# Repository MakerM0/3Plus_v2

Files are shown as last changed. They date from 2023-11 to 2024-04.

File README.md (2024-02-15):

# 3Plus_v2
a macro keyboard

[OSHWHUB](https://oshwhub.com/kakaka/Multi-function-macro-keyboard-3Plus20-version)

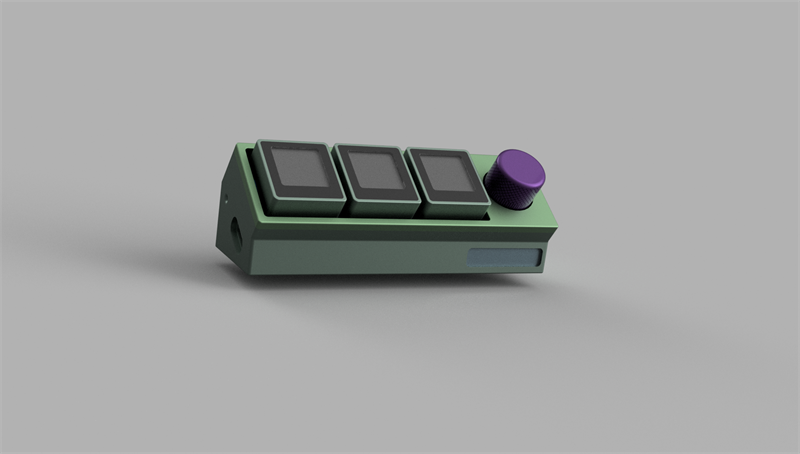
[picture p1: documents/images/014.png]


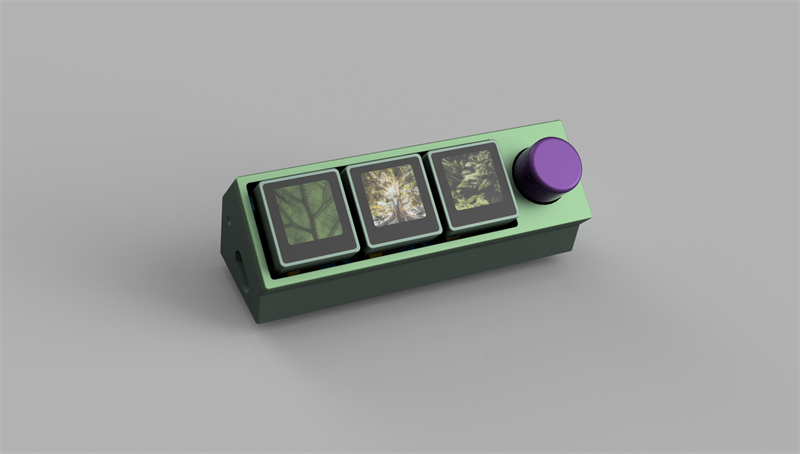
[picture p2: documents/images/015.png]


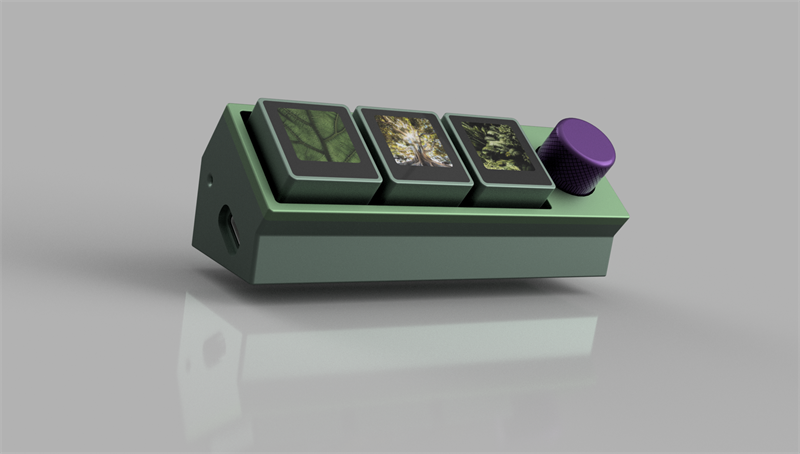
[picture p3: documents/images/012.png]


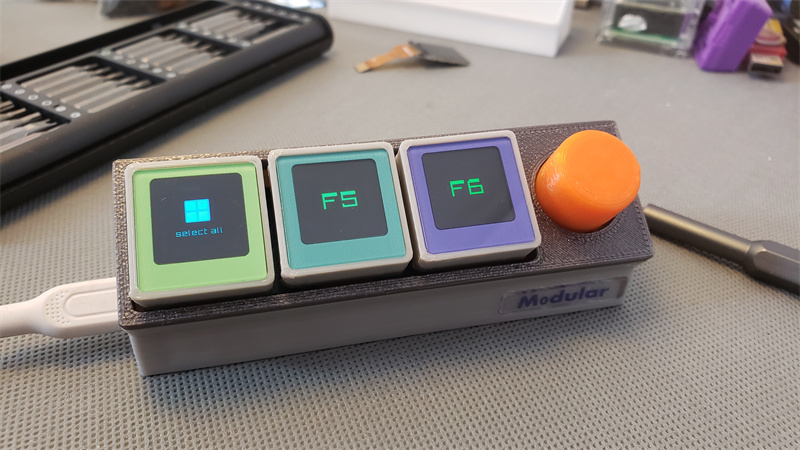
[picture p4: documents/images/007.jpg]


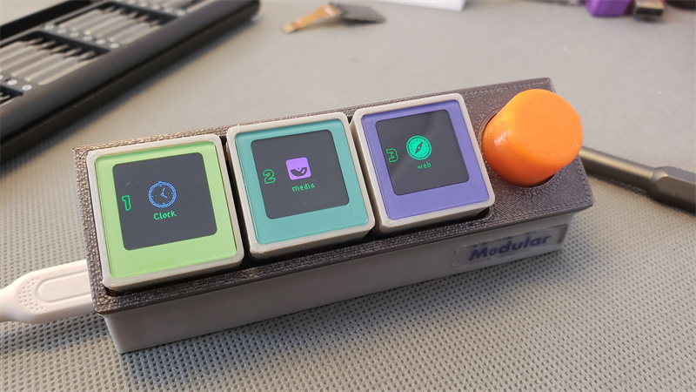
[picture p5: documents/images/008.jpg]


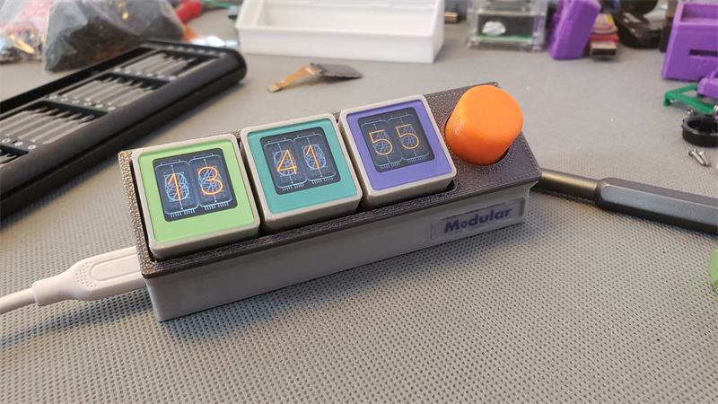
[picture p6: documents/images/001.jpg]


## Mechanical

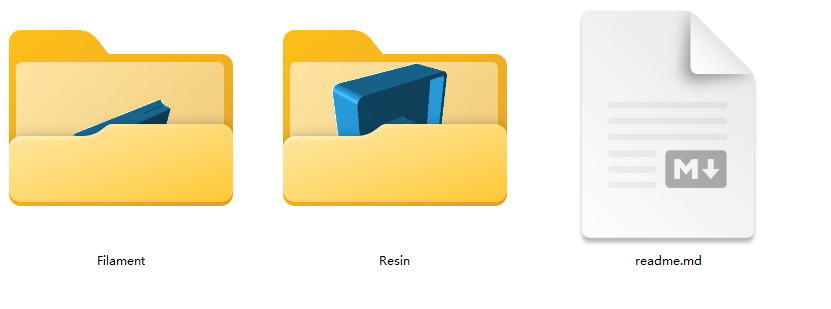
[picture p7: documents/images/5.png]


## License

(documents/hardware/mechanical)[Creative Commons — Attribution-NonCommercial-ShareAlike 4.0 International — CC BY-NC-SA 4.0](https://creativecommons.org/licenses/by-nc-sa/4.0/)

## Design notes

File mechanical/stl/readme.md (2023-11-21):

# Resin

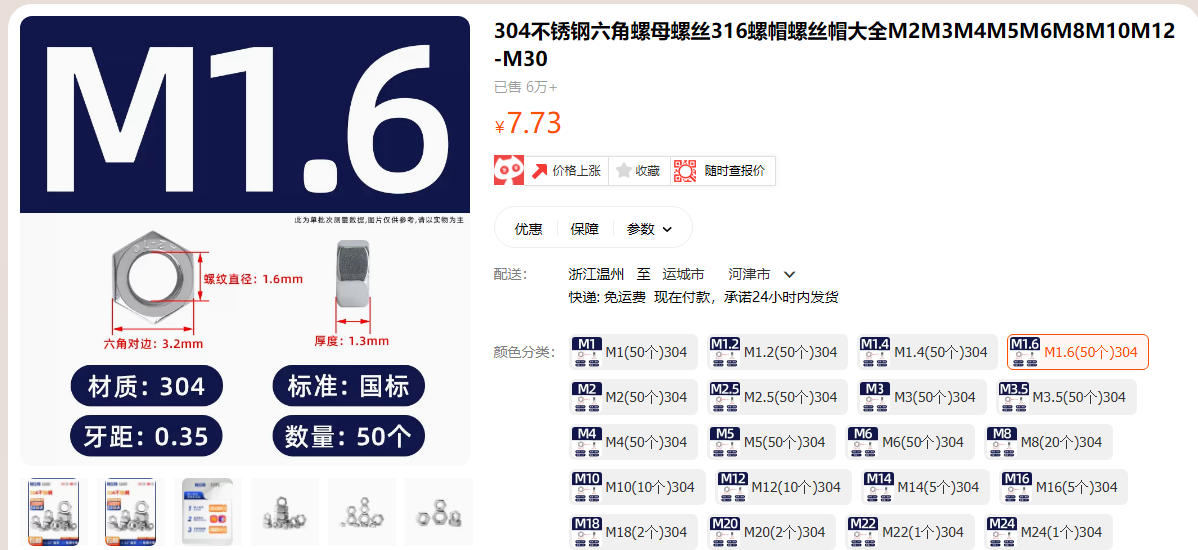
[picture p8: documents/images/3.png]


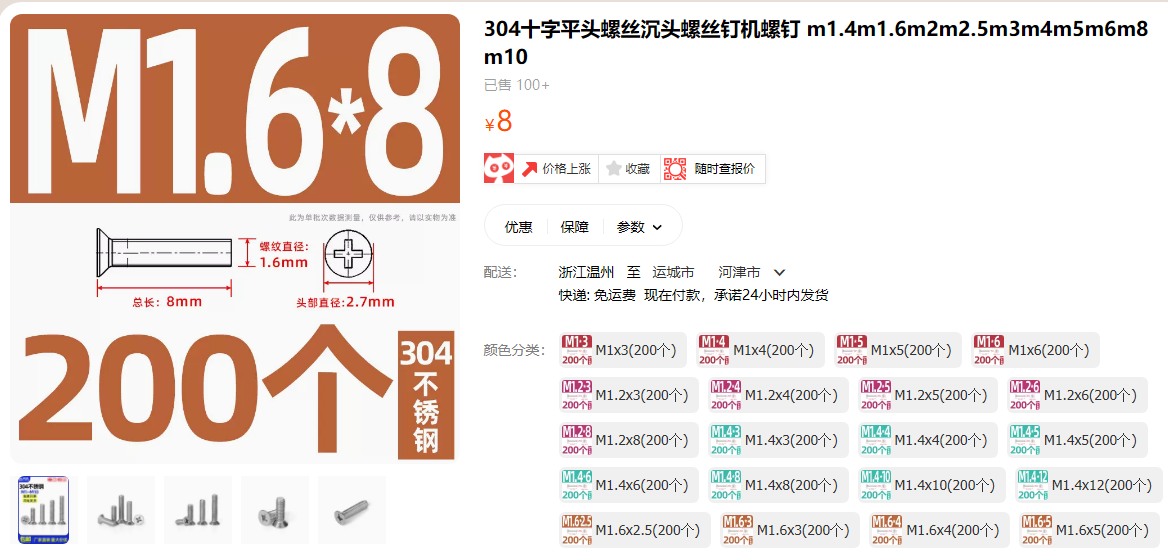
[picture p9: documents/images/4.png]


# Filament

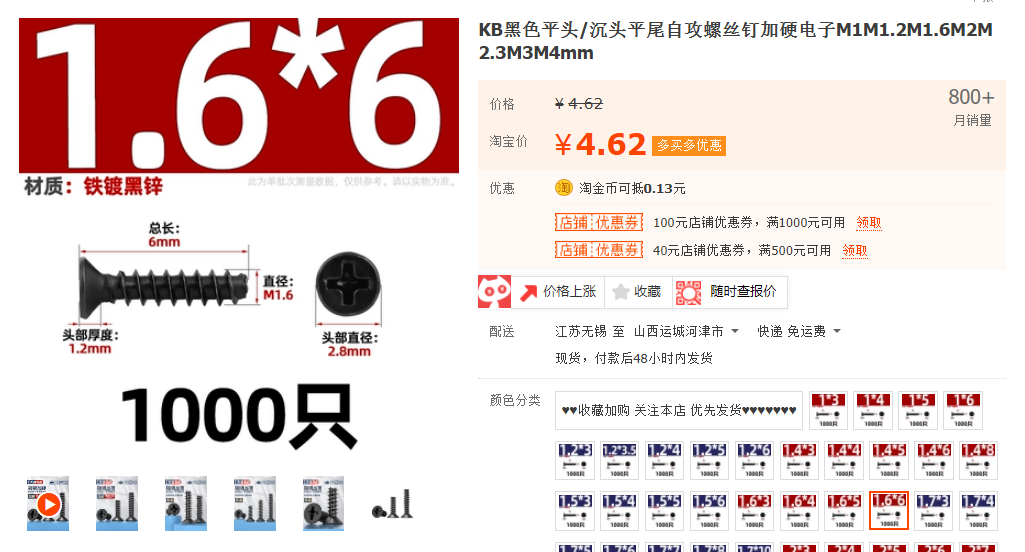
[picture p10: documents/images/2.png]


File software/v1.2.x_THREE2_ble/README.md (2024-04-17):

[多功能宏键盘 3Plus 【V2版本】 - 嘉立创EDA开源硬件平台 (oshwhub.com)](https://oshwhub.com/kakaka/Multi-function-macro-keyboard-3Plus20-version)

## 更新历史

### 20220901 【v1.0.0】

- 初始版本
- 时钟图片来源于https://github.com/JosueAGtz/displayArray/

### 20221024 【v1.0.2】

- 时钟增加1分钟随机切换显示，防烧屏
- 增加网络配置城市和wifi，通过重启状态下按下左数第三个按键
- 增加全字母键盘功能页
- 增加一键三连等
- 增加番茄钟
- spiffs迁移到littlefs
- 支持S3、C3

### 20221117 【v1.0.3】

- 增加三款时钟类型，时钟图片来源于https://github.com/JosueAGtz/displayArray/
- 修复一些小bug
- 增加几个网站快捷

### 20221125 【v1.0.4】

- 判断wifi的ssid等参数是否有填充

### 20221207 【v1.1.0】

- 使用WiFiManager修改wifi等参数
- 时钟类型自动添加
- 时钟部分重新修改，调整尺寸和类型，受限于资源区大小，时钟类型进行了缩减，只留下了我常用的
- 修复以前的一些bug
- 如果没有填充天气相关信息，请不要使用天气功能，可能会重启的
- 增加OTA升级，开机时，一直按住左数第三个按键，直到第三个屏幕出现OTA字样即可
- 如果想重新配置WIFI，开机时，一直按住左数第二个按键，屏幕会有提示

### 20231114 【v1.1.1】

- 增加esp32s3的支持，硬件升级为v2版本
- 更新部分库
- 使用WiFiManager修改wifi等参数
- 时钟图片大小调整
- 如果没有填充天气相关信息，请不要使用天气功能，可能会重启的
- 增加OTA升级，开机后，在出现三键客字样时，一直按住左数第3个按键，直到第三个屏幕出现OTA字样即可
- 如果想重新配置WIFI，开机时，一直按住左数第2个按键，屏幕会有提示
- 如果想进入boot模式，需在开机上电前按住左数第3个按键

### 20231121 【v1.2.0】

- 屏蔽天气、pcstate
- 增加宏定义控制audio的使用，在platform.ini中进行开关
- 快捷键，可以自定义按键，填充数组内容即可
- audio存在一个bug，若播放声音后，boot按钮（左数第三个）会失效；暂时解决，待后续跟进
- 在时钟界面，会整点报时

### 20240319 【v1.2.1】

- 添加led灯效

### 20240320 【v1.2.2】

- 修复web页面输入错误问题

### 20240417 【v1.2.3】

- 更新图形库arduino_gfx 1.4.6
- 在wifi配置页面增加编码器的参数配置（一般为2或者4）
- 显示界面的字体调整
- 显示屏增加OTA进度条指示
- b站界面调整

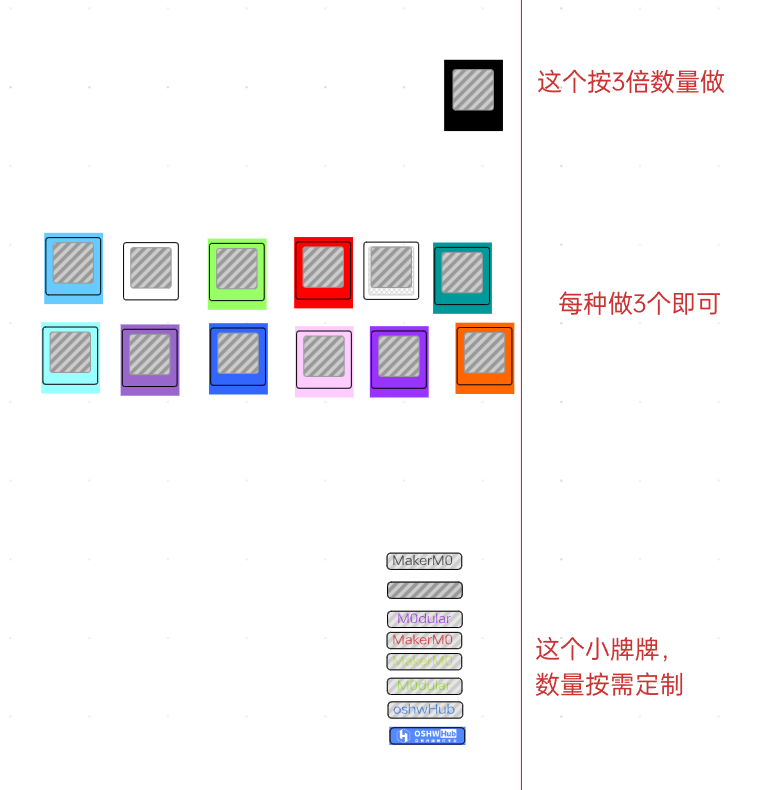
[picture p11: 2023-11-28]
mechanical/pannel/note.png

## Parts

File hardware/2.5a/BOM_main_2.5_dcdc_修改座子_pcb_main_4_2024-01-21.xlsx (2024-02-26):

No. | Quantity | Designator | Footprint | Manufacturer Part | Manufacturer | Supplier | Supplier Part | Value | Comment | JLCPCB Part Class
1 | 8 | C4,C5,C7,C8,C9,C206,C209,C211 | C0603 | CL10B104KB8NNNC | SAMSUNG(三星) | LCSC | C1591 | 100nF | 100nF | Extended Part
2 | 3 | C6,C10,C11 | C0603 | CL10A106KP8NNNC | SAMSUNG(三星) | LCSC | C19702 | 10uF | 10uF | Basic Part
3 | 3 | C204,C205,C213 | C0603 | CL10A105KB8NNNC | SAMSUNG(三星) | LCSC | C15849 | 1uF | 1uF | Basic Part
4 | 2 | C207,C210 | C0805 | CL21A226MAQNNNE | SAMSUNG(三星) | LCSC | C45783 | 22uF | 22uF | 基础库
5 | 1 | C208 | C0603 | CL10C220JB8NNNC | SAMSUNG(三星) | LCSC | C1653 | 22pF | 22pF | 基础库
6 | 2 | C214,C215 | C1206 | GRM31CR61A476ME15L | muRata(村田) | LCSC | C94034 | 47uF | 47uF | Extended Part
7 | 1 | D1 | sod-323_l1.8-w1.3-ls2.5-rd | 1N5819WS | Hottech(合科泰) | LCSC | C191023 |  | 1N5819WS | Basic Part
8 | 3 | FPC1,FPC2,FPC3 | FPC-SMD_12P-P0.50_FPC-05F-12PH20 | FPC-05F-12PH20 | XUNPU(讯普) | LCSC | C2856799 |  | FPC-05F-12PH20 | Extended Part
9 | 1 | L5 | IND-SMD_L4.0-W4.0 | YNR4030-2R2M | YJYCOIN(益嘉源) | LCSC | C340389 | 2.2uH | 2.2uH | Extended Part
10 | 1 | LED1 | LED0603-R-RD | 19-217/R6C-AL1M2VY/3T | EVERLIGHT(台湾亿光) | LCSC | C72044 |  | 19-217/R6C-AL1M2VY/3T | Extended Part
11 | 3 | LED2,LED3,LED4 | LED-SMD_4P-L4.0-W1.7_M4020-03003-RGB-862-001 | XL-4020RGBC-WS2812B | XINGLIGHT(成兴光) | LCSC | C3647024 |  | XL-4020RGBC-WS2812B | Extended Part
12 | 3 | MX1,MX2,MX3 | CherryMX(KHS)-1.00U | CPG151101S11-16 | Kailh(凯华) | LCSC | C5156480 |  | CPG151101S11-16 | Extended Part
13 | 1 | Q1 | SOT-23-3_L2.9-W1.3-P1.90-LS2.4-BR | AO3415 | Hottech(合科泰) | LCSC | C181094 |  | AO3415 | Extended Part
14 | 1 | Q200 | SOT-23-3_L2.9-W1.3-P1.90-LS2.4-BR | SS8050 | CJ（江苏长电/长晶） | LCSC | C2150 |  | SS8050 | BasicPart
15 | 2 | R1,R2 | R0603 | 0603WAF5101T5E | UNI-ROYAL(厚声) | LCSC | C23186 | 5.1kΩ | 5.1kΩ | Basic Part
16 | 4 | R5,R9,R10,R202 | R0603 | 0603WAF1002T5E | UNI-ROYAL(厚声) | LCSC | C25804 | 10kΩ | 10kΩ | Basic Part
17 | 4 | R13,R209,R214,R215 | R0603 | 0603WAF1003T5E | UNI-ROYAL(厚声) | LCSC | C25803 | 100kΩ | 100kΩ | Basic Part
18 | 2 | R16,R201 | R0603 | 0603WAF1001T5E | UNI-ROYAL(厚声) | LCSC | C21190 | 1kΩ | 1kΩ | Basic Part
19 | 1 | R204 | R0603 | 0603WAF1004T5E | UNI-ROYAL(厚声) | LCSC | C22935 | 1MΩ | 1MΩ | 基础库
20 | 3 | R205,R206,R207 | R0603 | 0603WAF200JT5E | UNI-ROYAL(厚声) | LCSC | C22950 | 20Ω | 20Ω | Basic Part
21 | 1 | R208 | R0603 | 0603WAF1501T5E | UNI-ROYAL(厚声) | LCSC | C22843 | 1.5kΩ | 1.5kΩ | Basic Part
22 | 1 | R211 | R0603 | 0603WAF2212T5E | UNI-ROYAL(厚声) | LCSC | C25961 | 22.1kΩ | 22.1kΩ | Extended Part
23 | 1 | SW102 | SW-SMD_EC11J1524413 | EC11J1524413 | ALPSALPINE(阿尔卑斯阿尔派) | LCSC | C470592 |  | EC11J1524413 | 扩展库
24 | 1 | SW111 | SW-TH_SK12D07VG4 | SK12D07VG4 | SHOU HAN(首韩) | LCSC | C393937 |  | SK12D07VG4 | Extended Part
25 | 1 | U1 | sot-23-5_l3.0-w1.7-p0.95-ls2.8-br | TP4054-42-SOT25R | TOPPOWER(南京拓微) | LCSC | C32574 |  | TP4054-42-SOT25R | Basic Part
26 | 1 | U205 | WIRELM-SMD_ESP32-S3-WROOM-1 | ESP32-S3-WROOM-1-N8R2 | ESPRESSIF(乐鑫) | LCSC | C2913204 |  | ESP32-S3-WROOM-1-N8R2 | Extended Part
27 | 1 | U206 | SOT-23-5_L3.0-W1.7-P0.95-LS2.8-BL | SY8088IAAC | silergy(矽力杰) | LCSC | C479072 |  | SY8088IAAC | 扩展库
28 | 1 | U207 | ESOP-8_L4.9-W3.9-P1.27-LS6.0-BL-EP-1 | NS4168 |  | LCSC | C9900042517 |  | NS4168
29 | 1 | USB2 | USB-C_SMD-TYPE-C-31-M-12 | USB-TYPE-C-018 | DEALON(德艺隆) | LCSC | C2927038 |  | USB-TYPE-C-018 | Extended Part

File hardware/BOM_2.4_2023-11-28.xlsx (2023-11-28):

No. | Quantity | Designator | Footprint | Manufacturer Part | Manufacturer | Supplier | Supplier Part | Value | Comment | JLCPCB Part Class
1 | 4 | C1,C2,C204,C205 | C0603 | CL10A105KB8NNNC | SAMSUNG(三星) | LCSC | C15849 | 1uF | 1uF | Basic Part
2 | 6 | C4,C5,C7,C8,C9,C35 | C0603 | CL10B104KB8NNNC | SAMSUNG(三星) | LCSC | C1591 | 100nF | 100nF | Extended Part
3 | 4 | C6,C10,C11,C34 | C0603 | CL10A106KP8NNNC | SAMSUNG(三星) | LCSC | C19702 | 10uF | 10uF | Basic Part
4 | 2 | C47,C48 | C0603 | 0603B681K500NT | FH(风华) | LCSC | C1630 | 680pF | 680pF | Basic Part
5 | 1 | D1 | sod-323_l1.8-w1.3-ls2.5-rd | 1N5819WS | Hottech(合科泰) | LCSC | C191023 |  | 1N5819WS | Basic Part
6 | 3 | FPC1,FPC2,FPC3 | CONN-SMD_12P-P0.50_L3.1-W8.0 | AFC42-S12FMA-1H | JS(钜硕电子) | LCSC | C466532 |  | AFC42-S12FMA-1H | 扩展库
7 | 2 | L3,L4 | L0603 | BLM18SG331TN1D | muRata(村田) | LCSC | C88989 |  | BLM18SG331TN1D | Extended Part
8 | 1 | LDO1 | SOT-23-5_L3.0-W1.7-P0.95-LS2.8-BR | TLV75733PDBVR | TI(德州仪器) | LCSC | C485517 |  | TLV75733PDBVR | Extended Part
9 | 1 | LED1 | LED0603-R-RD | 19-217/R6C-AL1M2VY/3T | EVERLIGHT(台湾亿光) | LCSC | C72044 |  | 19-217/R6C-AL1M2VY/3T | Extended Part
10 | 3 | MX1,MX2,MX3 | CherryMX(KHS)-1.00U | CPG151101S11-16 | Kailh(凯华) | LCSC | C5156480 |  | CPG151101S11-16 | Extended Part
11 | 1 | Q1 | sot-23-3_l2.9-w1.3-p1.90-ls2.4-br | AO3415 | Hottech(合科泰) | LCSC | C181094 |  | AO3415 | Extended Part
12 | 1 | Q200 | SOT-23-3_L2.9-W1.3-P1.90-LS2.4-BR | SS8050 | CJ（江苏长电/长晶） | LCSC | C2150 |  | SS8050 | BasicPart
13 | 2 | R1,R2 | R0603 | 0603WAF5101T5E | UNI-ROYAL(厚声) | LCSC | C23186 | 5.1kΩ | 5.1kΩ | Basic Part
14 | 4 | R5,R9,R10,R202 | R0603 | 0603WAF1002T5E | UNI-ROYAL(厚声) | LCSC | C25804 | 10kΩ | 10kΩ | Basic Part
15 | 2 | R13,R43 | R0603 | 0603WAF1003T5E | UNI-ROYAL(厚声) | LCSC | C25803 | 100kΩ | 100kΩ | Basic Part
16 | 3 | R16,R201,R208 | R0603 | 0603WAF1001T5E | UNI-ROYAL(厚声) | LCSC | C21190 | 1kΩ | 1kΩ | Basic Part
17 | 1 | R42 | R0603 | RC0603FR-07634KL | YAGEO(国巨) | LCSC | C273753 | 634kΩ | 634kΩ | Extended Part
18 | 1 | R204 | R0603 | 0603WAF1004T5E | UNI-ROYAL(厚声) | LCSC | C22935 | 1MΩ | 1MΩ | 基础库
19 | 3 | R205,R206,R207 | R0603 | 0603WAF200JT5E | UNI-ROYAL(厚声) | LCSC | C22950 | 20Ω | 20Ω | Basic Part
20 | 1 | SW102 | SW-SMD_EC11J1524413 | EC11J1524413 | ALPSALPINE(阿尔卑斯阿尔派) | LCSC | C470592 |  | EC11J1524413 | 扩展库
21 | 1 | SW104 | SW-SMD_TS36CA | TS36CA-0.6 | SHOU HAN(首韩) | LCSC | C2681481 |  | TS36CA-0.6 | 扩展库
22 | 3 | SW105,SW106,SW107 | KEY-TH_CPG1511F01S0X | CPG151101S13 | Kailh(凯华) | LCSC | C404353 |  | CPG151101S13 | 扩展库
23 | 1 | U1 | SOT-23-5_L3.0-W1.7-P0.95-LS2.8-BR | TP4054-42-SOT25R | TOPPOWER(南京拓微) | LCSC | C32574 |  | TP4054-42-SOT25R | Basic Part
24 | 1 | U15 | TQFN-16_L3.0-W3.0-P0.50-BL-EP1.5 | MAX98357AETE+T | ADI(亚德诺)/MAXIM(美信) | LCSC | C910544 |  | MAX98357AETE+T | Extended Part
25 | 1 | U205 | WIRELM-SMD_ESP32-S3-WROOM-1 | ESP32-S3-WROOM-1-N8R2 | ESPRESSIF(乐鑫) | LCSC | C2913204 |  | ESP32-S3-WROOM-1-N8R2 | Extended Part
26 | 1 | USB2 | USB-C_SMD-TYPE-C-31-M-12 | USB-TYPE-C-018 | DEALON(德艺隆) | LCSC | C2927038 |  | USB-TYPE-C-018 | Extended Part

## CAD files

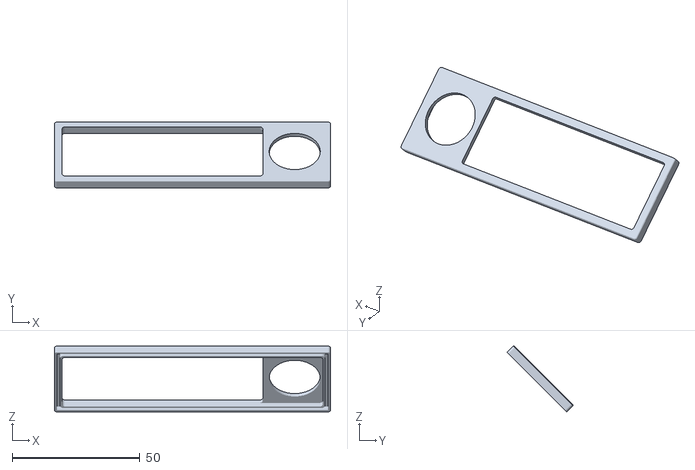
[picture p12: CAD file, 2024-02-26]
mechanical/stl/2.5/盖板.stl
108.0 x 25.7 x 25.7

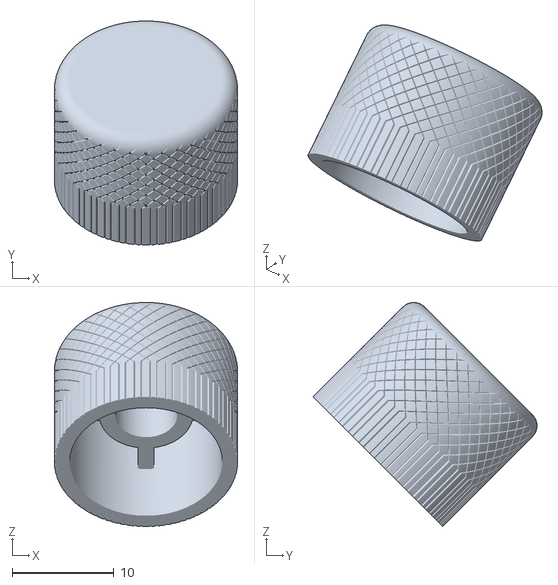
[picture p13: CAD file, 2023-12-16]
mechanical/stl/Filament/plus_旋钮_纹理_pla.stl
18.0 x 22.0 x 22.0

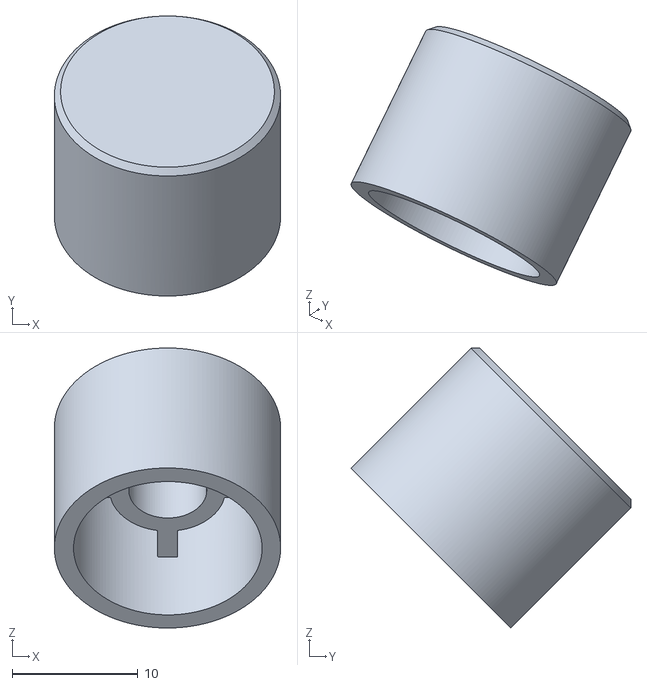
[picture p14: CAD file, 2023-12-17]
mechanical/stl/Resin/旋钮_光面_内孔扩大0.1mm.stl
18.0 x 22.3 x 22.3

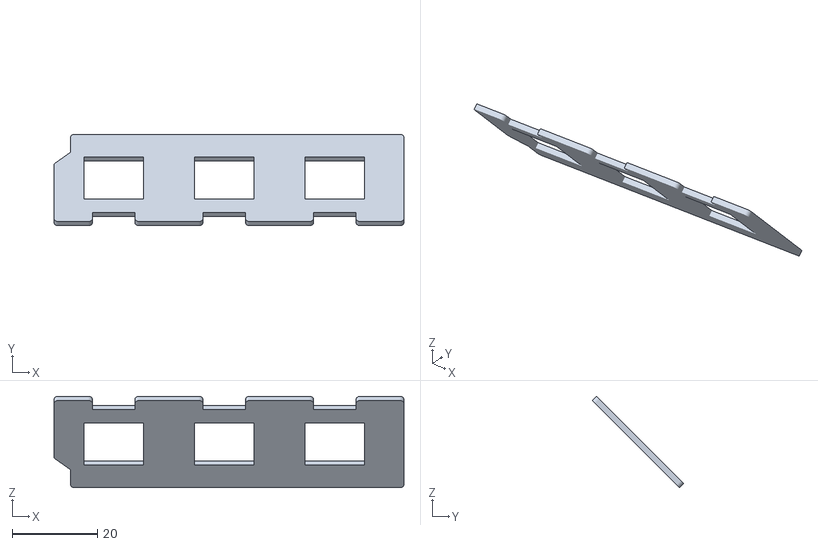
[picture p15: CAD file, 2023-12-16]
mechanical/stl/定位板_1.4mm.stl
82.3 x 21.5 x 21.5

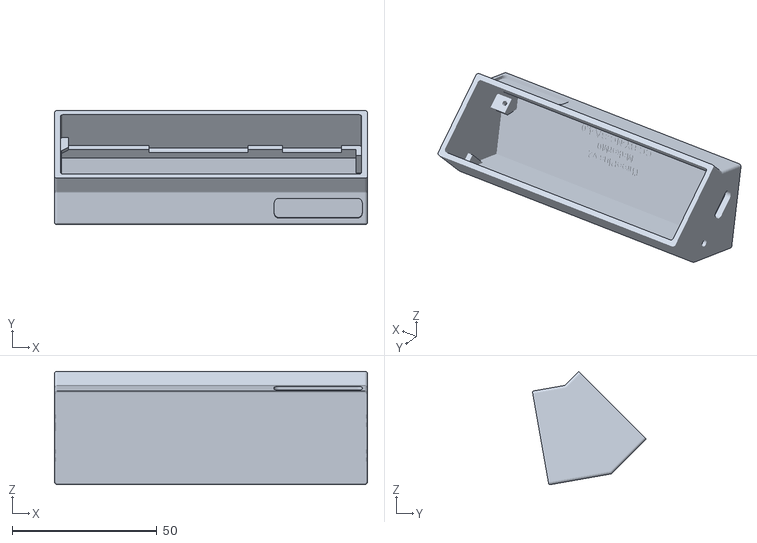
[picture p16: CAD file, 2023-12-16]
mechanical/stl/方案3/filament/plus_外壳 _pla_面板_与亚克力盖板配合.stl
108.0 x 39.3 x 39.1

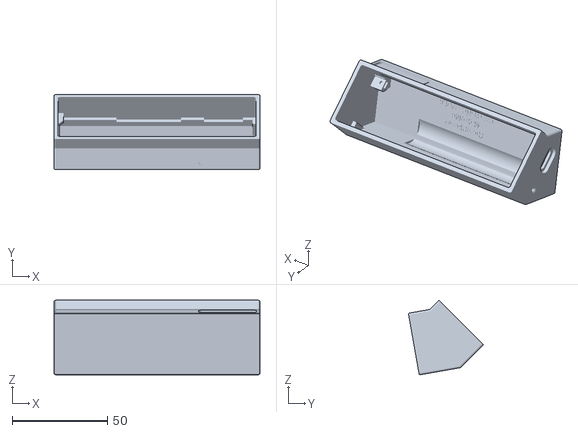
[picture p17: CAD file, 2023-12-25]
mechanical/stl/方案3/光固化/外壳 _面板_与亚克力盖板配合_14650带保护板锂电池.stl
108.0 x 39.3 x 39.1

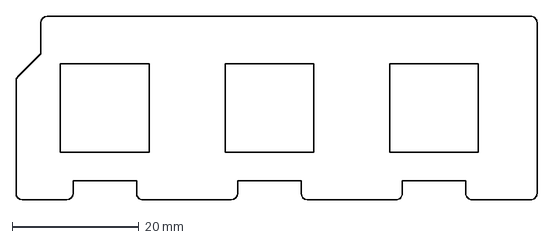
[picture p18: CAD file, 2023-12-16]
mechanical/stl/方案3/定位板.dxf
82.3 x 29.0 mm

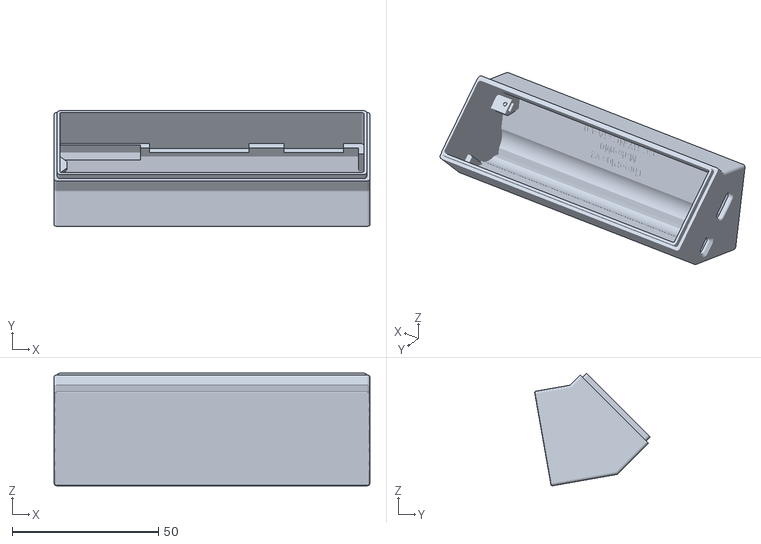
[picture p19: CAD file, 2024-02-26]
mechanical/stl/2.5/外壳.stl
108.0 x 39.5 x 38.5

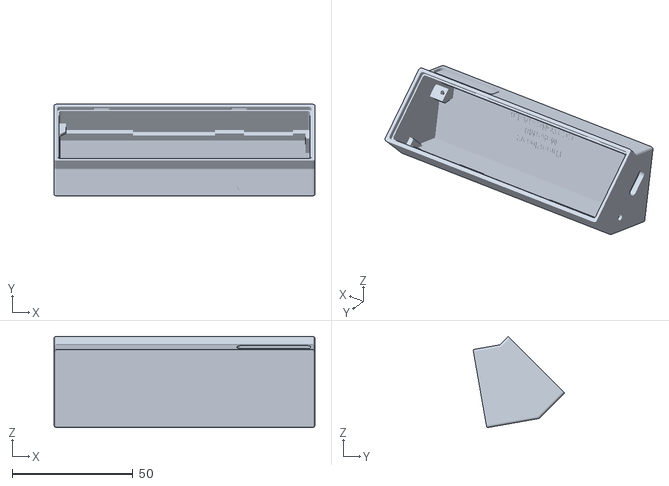
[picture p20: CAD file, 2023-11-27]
mechanical/stl/Filament/plus_外壳 _面板_pla.stl
108.0 x 37.9 x 37.7

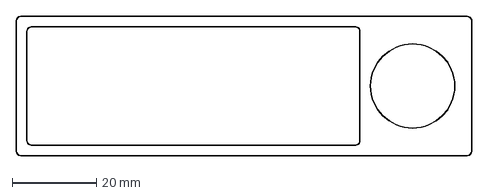
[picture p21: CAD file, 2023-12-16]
mechanical/stl/方案3/盖板-亚克力面板1.0mm.dxf
108.0 x 33.0 mm

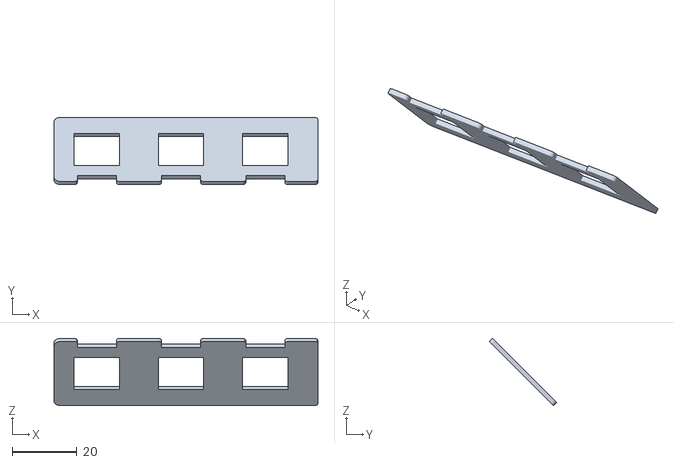
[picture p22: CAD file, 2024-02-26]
mechanical/stl/2.5/定位板.stl
81.5 x 20.8 x 20.8

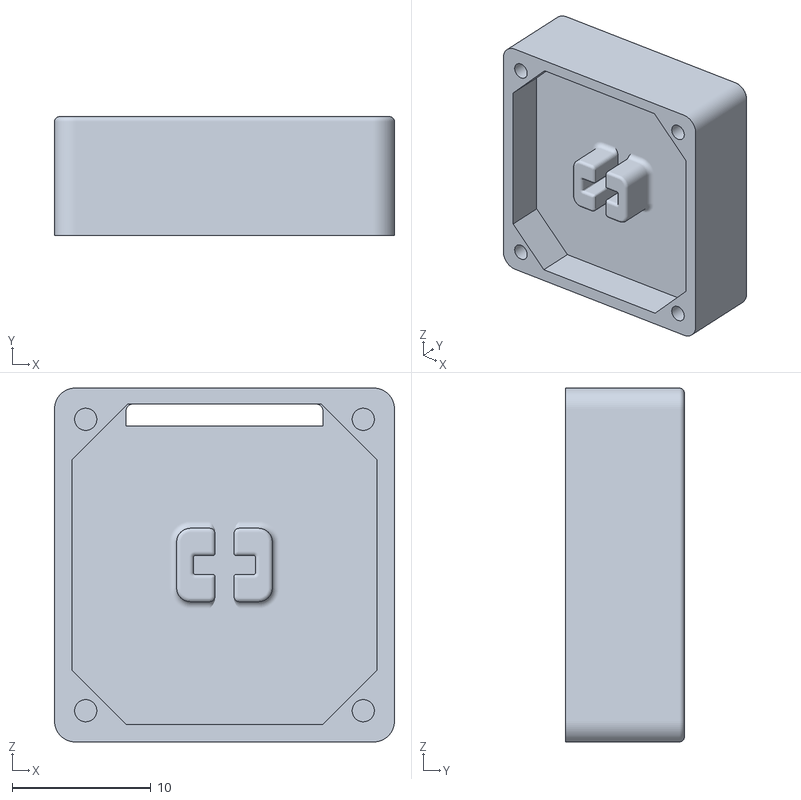
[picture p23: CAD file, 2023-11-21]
mechanical/stl/Filament/显示外壳 X3.stl
24.5 x 8.55 x 25.5

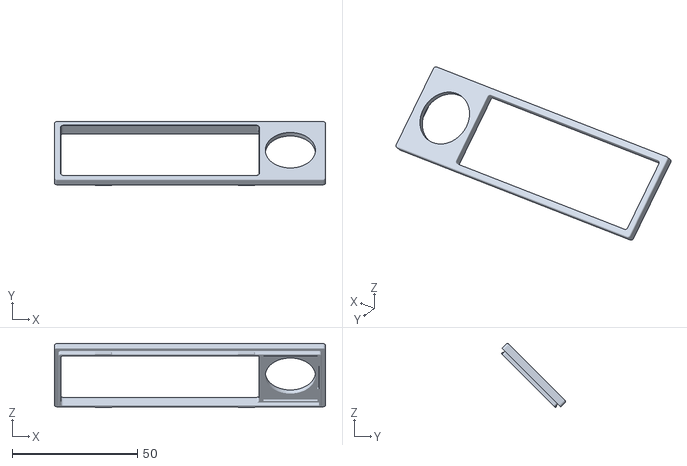
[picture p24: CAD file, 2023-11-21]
mechanical/stl/Filament/plus_盖板_pla.stl
108.0 x 25.5 x 25.5

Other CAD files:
mechanical/stl/Resin/旋钮_纹理_内孔扩大0.1mm.stl
mechanical/stl/方案3/光固化/外壳 _面板_与亚克力盖板配合.stl
mechanical/stl/Resin/外壳 _面板.stl
mechanical/stl/2.5/旋钮_光面.stl
mechanical/stl/Resin/外壳_刻字.stl
mechanical/stl/2.5/显示外壳 x3.stl
mechanical/stl/Resin/旋钮_光面_2.4.stl
mechanical/stl/Resin/旋钮_纹理_2.4.stl
mechanical/stl/Resin/盖板.stl

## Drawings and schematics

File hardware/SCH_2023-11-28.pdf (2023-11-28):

## VSYS

## VSYS

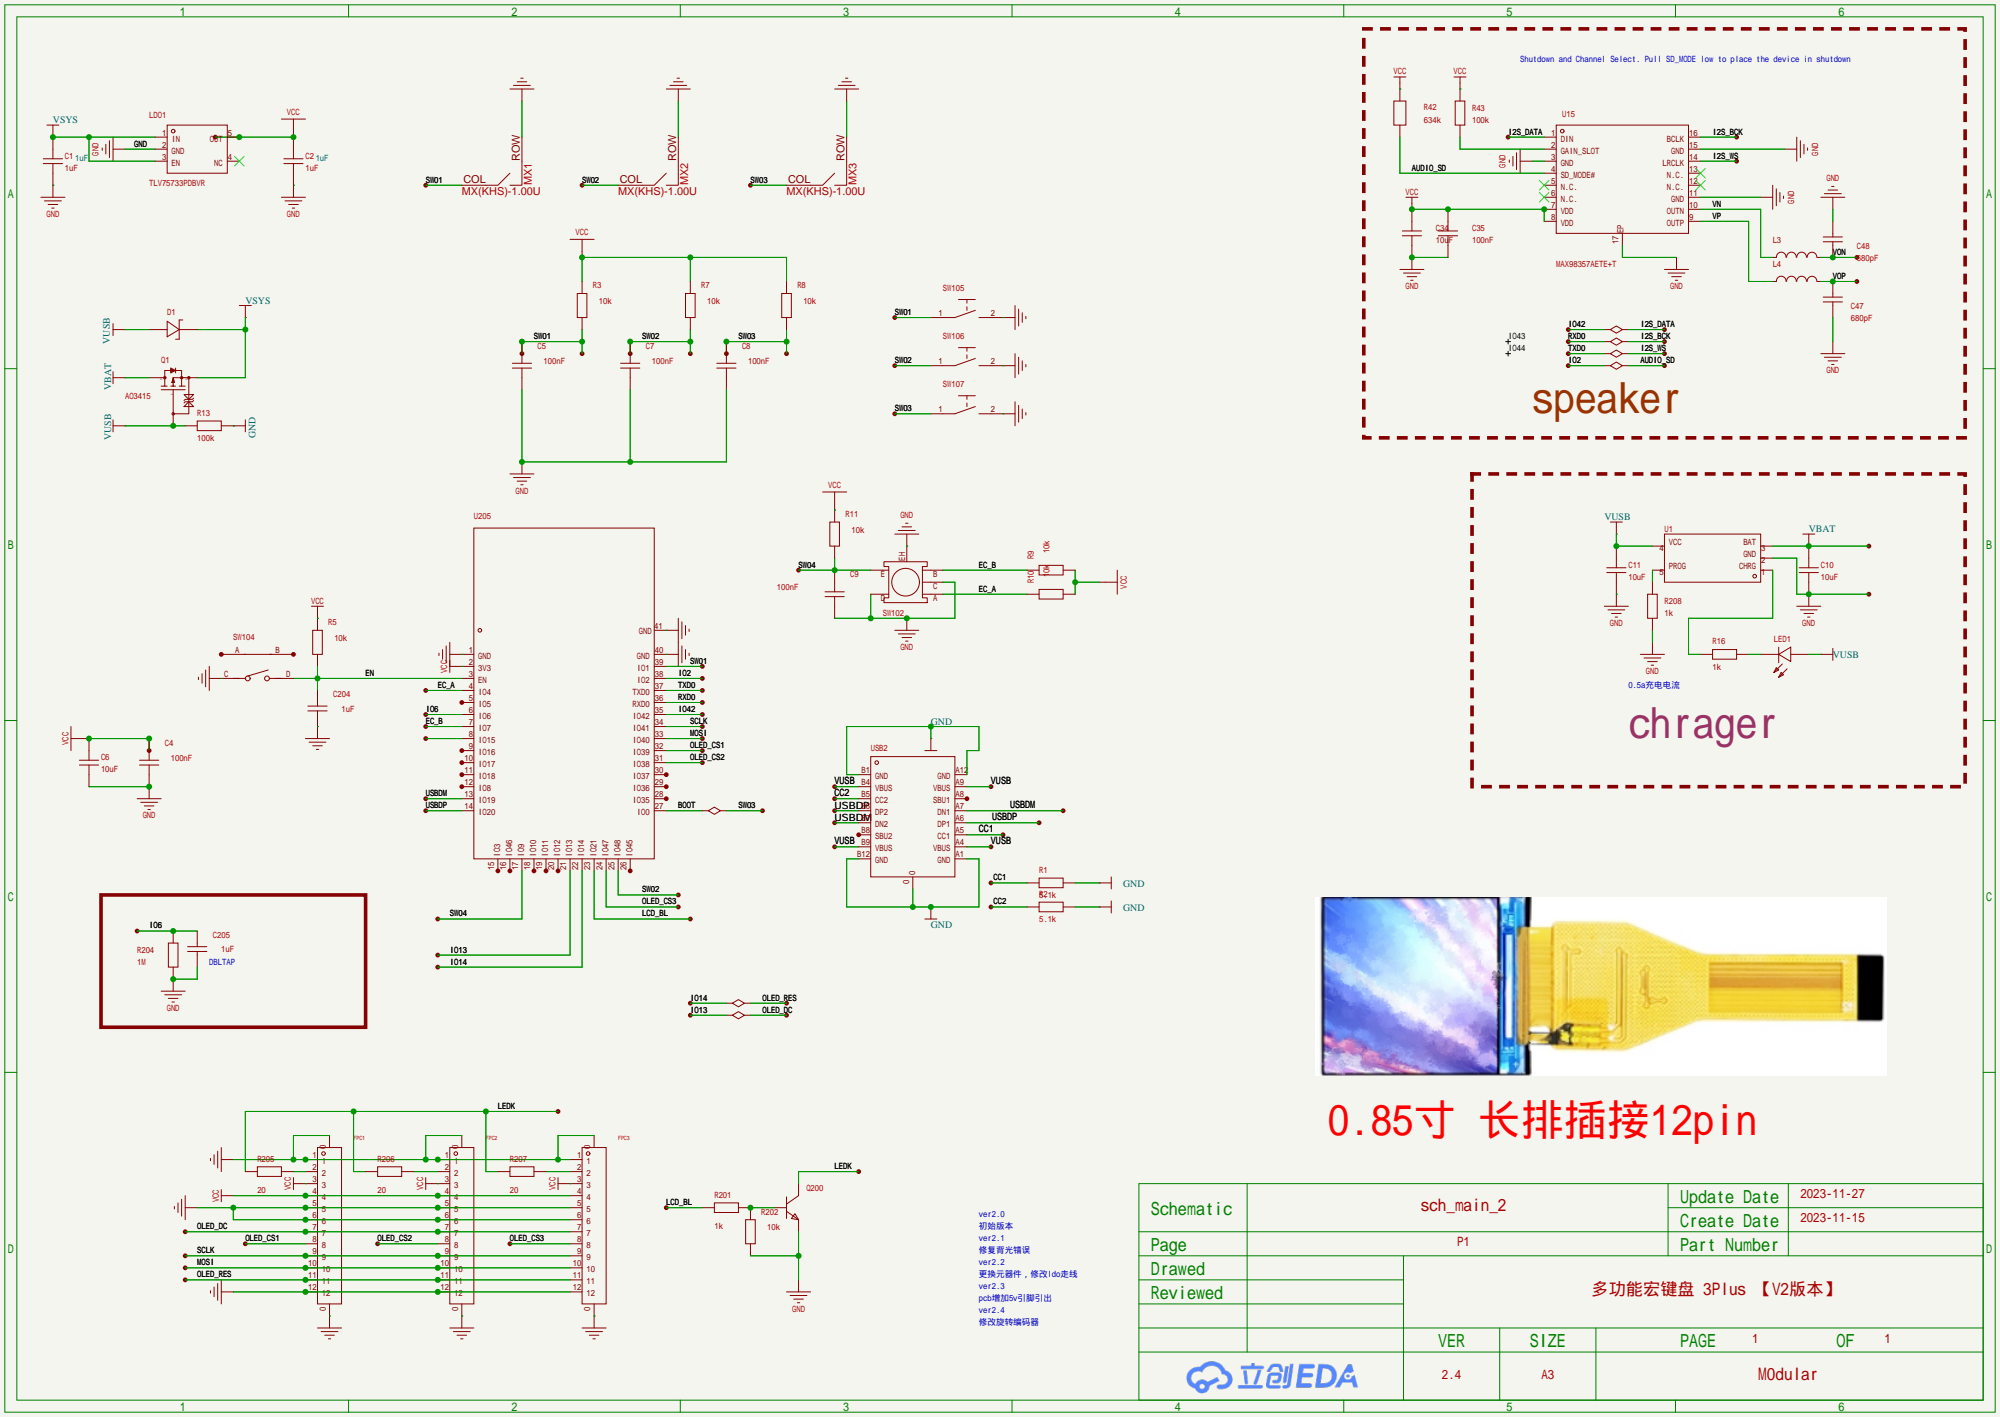
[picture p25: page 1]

Shutdown and Channel Select. Pull SD_MODE low to place the device in shutdown

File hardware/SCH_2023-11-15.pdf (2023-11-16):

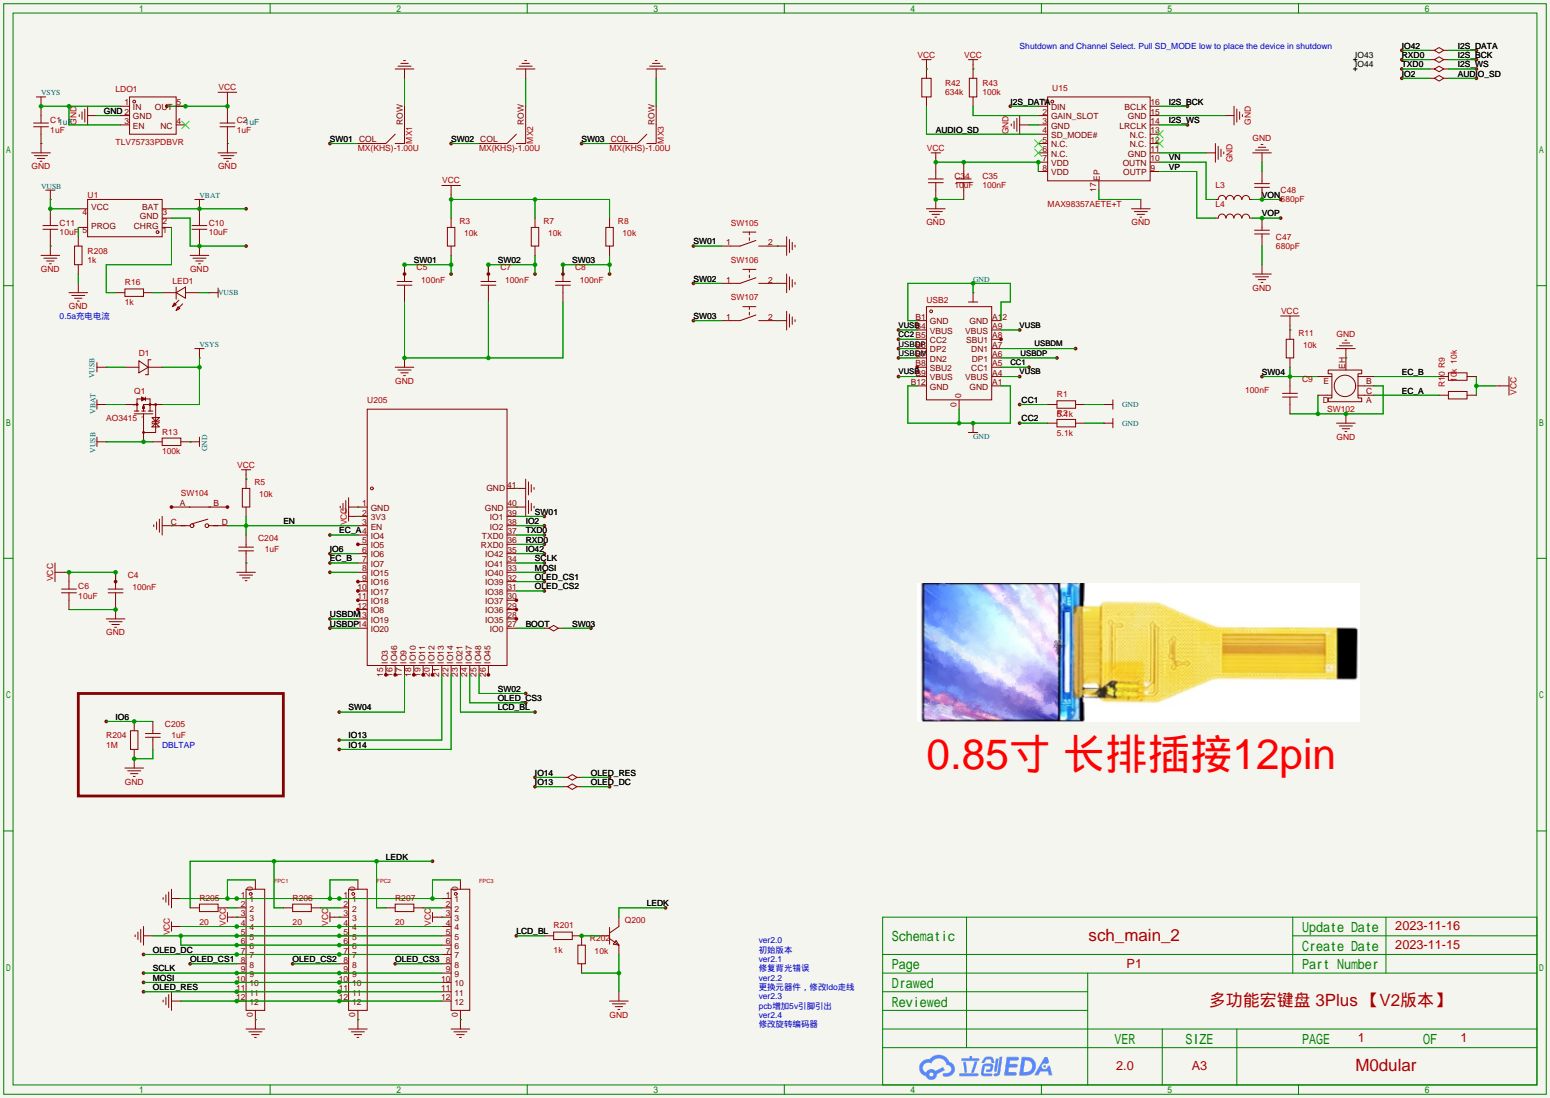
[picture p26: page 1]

Shutdown and Channel Select. Pull SD_MODE low to place the device in shutdown

OUTN 10 GND 11 N.C. 12 N.C. 13 LRCLK 14 GND 15 BCLK 16

GND A1 VBUS A4 CC1 A5 DP1 A6 DN1 A7 SBU1 A8 VBUS A9 GND A12

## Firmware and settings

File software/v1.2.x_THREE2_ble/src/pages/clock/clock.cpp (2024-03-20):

#include "clock.h"
#include "board_def.h"
#include "app/app_key.h"
#include "app/app_audio.h"
#include "app/app_led.h"
const char *number_name[] = {"zero", "one", "two", "three", "four", "five", "six", "seven", "eight", "nine"};
// char *clock_name[] = {"matrix", "nixie", "vfd", "digital", "14seg", "bina", "flip", "ink", "purple", "cyan", "nimo", "wood", "pixiepro", "predator", "rgb", "dhf"};

String clock_name[36];
static uint8_t CLOCK_TYPE_MAX = 0;
static int8_t clock_type_index ;
bool f_updateall = false;
static uint8_t num_old[6] = {0xff, 0xff, 0xff, 0xff, 0xff, 0xff};

#define POS_Y 0

static uint8_t xpos=64;

void dispTime(uint8_t hour, uint8_t min, uint8_t sec)
{
	char path[100];

	// gfx1->setCursor(0, 0);
	// gfx1->setTextSize(8);
	// gfx1->setTextColor(random(0xffff), BLACK);
	// gfx1->printf("%02d", hour);
	// gfx1->draw16bitBeRGBBitmap(0, POS_Y, (uint16_t *)clock_img[hour / 10], xpos, 96);
	// gfx1->draw16bitBeRGBBitmap(xpos, POS_Y, (uint16_t *)clock_img[hour % 10], xpos, 96);
	if (num_old[0] != hour / 10 || f_updateall)
	{
		num_old[0] = hour / 10;
		sprintf(path, "/clock_theme/%s/%s.png", clock_name[clock_type_index], number_name[hour / 10]);
		myDrawPNG(0, POS_Y, path, 0);
	}
	if (num_old[1] != hour % 10 || f_updateall)
	{
		num_old[1] = hour % 10;
		sprintf(path, "/clock_theme/%s/%s.png", clock_name[clock_type_index], number_name[hour % 10]);
		myDrawPNG(xpos, POS_Y, path, 0);
	}

	// gfx2->setCursor(0, 0);
	// gfx2->setTextSize(8);
	// gfx2->setTextColor(random(0xffff), BLACK);
	// gfx2->printf("%02d", min);
	// gfx2->draw16bitBeRGBBitmap(0, POS_Y, (uint16_t *)clock_img[min / 10], xpos, 96);
	// gfx2->draw16bitBeRGBBitmap(xpos, POS_Y, (uint16_t *)clock_img[min % 10], xpos, 96);
	if (num_old[2] != min / 10 || f_updateall)
	{
		num_old[2] = min / 10;
		sprintf(path, "/clock_theme/%s/%s.png", clock_name[clock_type_index], number_name[min / 10]);
		myDrawPNG(0, POS_Y, path, 1);
	}
	if (num_old[3] != min % 10 || f_updateall)
	{
		num_old[3] = min % 10;
		sprintf(path, "/clock_theme/%s/%s.png", clock_name[clock_type_index], number_name[min % 10]);
		myDrawPNG(xpos, POS_Y, path, 1);
	}

	// gfx3->setCursor(0, 0);
	// gfx3->setTextSize(8);
	// gfx3->setTextColor(random(0xffff), BLACK);
	// gfx3->printf("%02d", sec);
	// gfx3->draw16bitBeRGBBitmap(0, POS_Y, (uint16_t *)clock_img[sec / 10], xpos, 96);
	// gfx3->draw16bitBeRGBBitmap(xpos, POS_Y, (uint16_t *)clock_img[sec % 10], xpos, 96);
	if (num_old[4] != sec / 10 || f_updateall)
	{
		num_old[4] = sec / 10;
		sprintf(path, "/clock_theme/%s/%s.png", clock_name[clock_type_index], number_name[sec / 10]);
		myDrawPNG(0, POS_Y, path, 2);
	}
	if (num_old[5] != sec % 10 || f_updateall)
	{
		num_old[5] = sec % 10;
		sprintf(path, "/clock_theme/%s/%s.png", clock_name[clock_type_index], number_name[sec % 10]);
		myDrawPNG(xpos, POS_Y, path, 2);
	}

	f_updateall = false;
}

//防止烧屏，一分钟切换一次界面风格显示
void dispTimeX(uint8_t hour, uint8_t min, uint8_t sec)
{
	char path[100];

	static int8_t index = random(CLOCK_TYPE_MAX);
	if (sec == 0)
	{
		index++;
		if (index >= CLOCK_TYPE_MAX)
		{
			index = 0;
		}
		f_updateall = true;
	}

	if (num_old[0] != hour / 10 || f_updateall)
	{
		num_old[0] = hour / 10;
		sprintf(path, "/clock_theme/%s/%s.png", clock_name[index], number_name[hour / 10]);
		// Serial.println(index);
		// Serial.println(clock_name[index]);

		myDrawPNG(0, POS_Y, path, 0);
	}
	if (num_old[1] != hour % 10 || f_updateall)
	{
		num_old[1] = hour % 10;
		sprintf(path, "/clock_theme/%s/%s.png", clock_name[index], number_name[hour % 10]);

		myDrawPNG(xpos, POS_Y, path, 0);
	}

	if (num_old[2] != min / 10 || f_updateall)
	{
		num_old[2] = min / 10;
		sprintf(path, "/clock_theme/%s/%s.png", clock_name[index], number_name[min / 10]);

		myDrawPNG(0, POS_Y, path, 1);
	}
	if (num_old[3] != min % 10 || f_updateall)
	{
		num_old[3] = min % 10;
		sprintf(path, "/clock_theme/%s/%s.png", clock_name[index], number_name[min % 10]);

		myDrawPNG(xpos, POS_Y, path, 1);
	}

	if (num_old[4] != sec / 10 || f_updateall)
	{
		num_old[4] = sec / 10;
		sprintf(path, "/clock_theme/%s/%s.png", clock_name[index], number_name[sec / 10]);

		myDrawPNG(0, POS_Y, path, 2);
	}
	if (num_old[5] != sec % 10 || f_updateall)
	{
		num_old[5] = sec % 10;
		sprintf(path, "/clock_theme/%s/%s.png", clock_name[index], number_name[sec % 10]);

		myDrawPNG(xpos, POS_Y, path, 2);
	}

	f_updateall = false;
}
// code from https://github.com/VolosR/SimplestFontTTGO/blob/main/TTGONumbersFont/TTGONumbersFont.ino
const byte arr[10][5][3] =
	{
		{{1, 1, 1}, // 0
		 {1, 0, 1},
		 {1, 0, 1},
		 {1, 0, 1},
		 {1, 1, 1}

		},
		{{0, 1, 0}, // 1
		 {0, 1, 0},
		 {0, 1, 0},
		 {0, 1, 0},
		 {0, 1, 0}

		},
		{{1, 1, 1}, // 2
		 {0, 0, 1},
		 {1, 1, 1},
		 {1, 0, 0},
		 {1, 1, 1}

		},
		{{1, 1, 1}, // 3
		 {0, 0, 1},
		 {1, 1, 1},
		 {0, 0, 1},
		 {1, 1, 1}

		},
		{{1, 0, 1}, // 4
		 {1, 0, 1},
		 {1, 1, 1},
		 {0, 0, 1},
		 {0, 0, 1}

		},
		{{1, 1, 1}, // 5
		 {1, 0, 0},
		 {1, 1, 1},
		 {0, 0, 1},
		 {1, 1, 1}

		},
		{{1, 1, 1}, // 6
		 {1, 0, 0},
		 {1, 1, 1},
		 {1, 0, 1},
		 {1, 1, 1}

		},
		{{1, 1, 1}, // 7
		 {0, 0, 1},
		 {0, 0, 1},
		 {0, 0, 1},
		 {0, 0, 1}

		},
		{{1, 1, 1}, // 8
		 {1, 0, 1},
		 {1, 1, 1},
		 {1, 0, 1},
		 {1, 1, 1}

		},
		{{1, 1, 1}, // 9
		 {1, 0, 1},
		 {1, 1, 1},
		 {0, 0, 1},
		 {1, 1, 1}

		}};

short colors[2] = {BLACK, GREEN}; // first colour is color of background , second is color of digit

int sizee = 20;	   // size of each box
byte space = 8;	   // space between boxes
int fromTop = 14;  // positon x
int fromLeft = 10; // position y
int Round = 0;

short number = 0;
int digits = 0;

void dispDotNum(int number, Arduino_GFX *gfx)
{
	String n = String(number);

	for (int z = 0; z < n.length(); z++)
		for (int i = 0; i < 5; i++)
			for (int j = 0; j < 3; j++)
			{
				String c = n.substring(z, z + 1);
				int b = c.toInt();

				gfx->fillRoundRect((z * (sizee * 4)) + fromLeft + (j * sizee) + (j * space), fromTop + (i * sizee) + (i * space), sizee, sizee, Round, colors[arr[b][i][j]]);
				// delay(20);
			}
}

int pos = 0;
int x = 0;
int y = 30;
int changeX = 1;
int changeY = 1;

void dispTimeDot(uint8_t hour, uint8_t min, uint8_t sec)
{

	delay(400);
	number++;

	if (number == 100)
		number = 0;

	f_updateall = false;
}

//获取时钟类型数目
void listDir(fs::FS &fs, const char *dirname, uint8_t levels)
{
	// Serial.printf("Listing directory: %s\r\n", dirname);

	File root = fs.open(dirname);
	if (!root)
	{
		// Serial.println("- failed to open directory");
		return;
	}
	if (!root.isDirectory())
	{
		// Serial.println(" - not a directory");
		return;
	}

	File file = root.openNextFile();
	while (file)
	{
		if (file.isDirectory())
		{
			// Serial.print("  DIR : ");
			// Serial.println(file.name());
			clock_name[CLOCK_TYPE_MAX] = file.name();
			// Serial.println(clock_name[dir_num]);
			CLOCK_TYPE_MAX++;

			if (levels)
			{
				listDir(fs, file.path(), levels - 1);
			}
		}

		file = root.openNextFile();
	}
}

static void init(void *data)
{
	if (CLOCK_TYPE_MAX == 0)
	{
		//获取时钟类型数目
		listDir(LittleFS, "/clock_theme/", 1);

		Serial.println(CLOCK_TYPE_MAX);
		clock_type_index = CLOCK_TYPE_MAX;
	}
	 
	for (uint8_t i = 0; i < 6; i++)
	{
		num_old[i] = 0xff;
	}
	// clock_type_index=12;
}

static void enter(void *data)
{
	// insert code
	gfx1->fillScreen(BLACK);
	gfx2->fillScreen(BLACK);
	gfx3->fillScreen(BLACK);
	//
	manager_setBusy(false); 

}
uint32_t t_old, t_now = 0;
uint8_t hour, minute, second = 0;

uint32_t t_led_now, t_led_old;

static void loop(void *data)
{
	KEY_TYPE key;

	t_now = millis();
	if (t_now - t_old >= 1000)
	{
		t_old = t_now;
		if (getLocalTime(&timeInfo))
		{

			if (clock_type_index == CLOCK_TYPE_MAX)
			{
				dispTimeX(timeInfo.tm_hour, timeInfo.tm_min, timeInfo.tm_sec);
			}
			else
			{
				dispTime(timeInfo.tm_hour, timeInfo.tm_min, timeInfo.tm_sec);
			}

			if (timeInfo.tm_min==0 && timeInfo.tm_sec==0  && timeInfo.tm_hour>7 &&timeInfo.tm_hour<23)
			{
				app_audio_sayTimeCN(timeInfo.tm_hour, timeInfo.tm_min);
			}

			// Serial.printf("%02d:%02d:%02d\r\n", timeInfo.tm_hour, timeInfo.tm_min, timeInfo.tm_sec);
		}
	}
	// t_led_now = millis();
	// if (t_led_now - t_led_old >= 500)
	// {
	// 	t_led_old = t_led_now;

	// 	rainbow(0);
	// 	app_led_update();
	// }

	key = app_key_get();
	switch (key)
	{

	case KEY1_SHORT:
	case KEY2_SHORT:
	// case KEY3_SHORT:
		getLocalTime(&timeInfo);
		app_audio_sayTimeCN(timeInfo.tm_hour, timeInfo.tm_min);
		break;

	case KEY4_LONG:				  //长按
		manager_switchToParent(); //进入父项目 //退出
		break;

	case ENC_NEXT:
		clock_type_index++;
		if (clock_type_index >= (CLOCK_TYPE_MAX + 1))
		{
			clock_type_index = 0;
		}
		f_updateall = true;
		if (clock_type_index == CLOCK_TYPE_MAX)
		{
			dispTimeX(timeInfo.tm_hour, timeInfo.tm_min, timeInfo.tm_sec);
		}
		else
		{
			dispTime(timeInfo.tm_hour, timeInfo.tm_min, timeInfo.tm_sec);
		}
		break;
	case ENC_PREV:
		clock_type_index--;
		if (clock_type_index < 0)
		{
			clock_type_index = CLOCK_TYPE_MAX;
		}
		f_updateall = true;
		if (clock_type_index == CLOCK_TYPE_MAX)
		{
			dispTimeX(timeInfo.tm_hour, timeInfo.tm_min, timeInfo.tm_sec);
		}
		else
		{
			dispTime(timeInfo.tm_hour, timeInfo.tm_min, timeInfo.tm_sec);
		}
		break;
	default:
		break;
	}
}

static void exit(void *data)
{

	manager_setBusy(true);
}
#include "img.h"
page_t page_clock = {
	.init = init,
	.enter = enter,
	.exit = exit,
	.loop = loop,
	.title_en = "Clock",
	.title_cn = "时间",
	.icon = img_bits,
	.icon_width = img_width,
	.icon_height = img_height,
	.sleep_enable = false,
	.wakeup_btn_effect_enable = false,
	.acc_enable = false,

};

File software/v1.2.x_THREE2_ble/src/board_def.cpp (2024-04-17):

#include "board_def.h"

WiFiManager wm;



#include <ESPAsyncWebServer.h>
#include <ElegantOTA.h>
AsyncWebServer server(80);

char stored_weather_key[40];
char stored_weather_city[40];
int rotary_factor=2;
char stored_rotary[10]; // 旋转编码器配置，默认2

class IntParameter : public WiFiManagerParameter {
public:
    IntParameter(const char *id, const char *placeholder, long value, const uint8_t length = 10)
        : WiFiManagerParameter("") {
        init(id, placeholder, String(value).c_str(), length, "", WFM_LABEL_BEFORE);
    }

    long getValue() {
        return String(WiFiManagerParameter::getValue()).toInt();
    }
};

BleKeyboard bleKeyboard(VER_HW, "M0dular", 100);

// flag for saving data
bool shouldSaveConfig = false;

// callback notifying us of the need to save config
void saveConfigCallback()
{
    Serial.println("Should save config");
    shouldSaveConfig = true;
}

struct tm timeInfo;

Button2 button1, button2, button3, button4;

// Change these two numbers to the pins connected to your encoder.
//   Best Performance: both pins have interrupt capability
//   Good Performance: only the first pin has interrupt capability
//   Low Performance:  neither pin has interrupt capability
Encoder myEnc(PIN_EC_A, PIN_EC_B);

int rst = PIN_RST;
int backlight = PIN_BL;

int mosi = PIN_MOSI;
int sclk = PIN_SCLK;
int dc = PIN_DC;

int cs1 = PIN_CS1;
int cs2 = PIN_CS2;
int cs3 = PIN_CS3;

/* More data bus class: https://github.com/moononournation/Arduino_GFX/wiki/Data-Bus-Class */
Arduino_DataBus *bus1 = new Arduino_ESP32SPI(dc /*dc*/, cs1 /*cs*/, sclk /*sclk*/, mosi /*mosi*/);
// Arduino_DataBus *bus1 = new Arduino_SWSPI(dc /*dc*/, cs1 /*cs*/, sclk /*sclk*/, mosi /*mosi*/,GFX_NOT_DEFINED /*miso*/);
/* More display class: https://github.com/moononournation/Arduino_GFX/wiki/Display-Class */
Arduino_GFX *gfx1 = new Arduino_NV3023(bus1, -1, 2 /* rotation */, false, 128, 128);

/* More data bus class: https://github.com/moononournation/Arduino_GFX/wiki/Data-Bus-Class */
Arduino_DataBus *bus2 = new Arduino_ESP32SPI(dc /*dc*/, cs2 /*cs*/, sclk /*sclk*/, mosi /*mosi*/);
// Arduino_DataBus *bus2 = new Arduino_SWSPI(dc /*dc*/, cs2 /*cs*/, sclk /*sclk*/, mosi /*mosi*/,GFX_NOT_DEFINED /*miso*/);

/* More display class: https://github.com/moononournation/Arduino_GFX/wiki/Display-Class */
Arduino_GFX *gfx2 = new Arduino_NV3023(bus2, -1, 2 /* rotation */, false, 128, 128);

/* More data bus class: https://github.com/moononournation/Arduino_GFX/wiki/Data-Bus-Class */
Arduino_DataBus *bus3 = new Arduino_ESP32SPI(dc /*dc*/, cs3 /*cs*/, sclk /*sclk*/, mosi /*mosi*/);
// Arduino_DataBus *bus3 = new Arduino_SWSPI(dc /*dc*/, cs3 /*cs*/, sclk /*sclk*/, mosi /*mosi*/,GFX_NOT_DEFINED /*miso*/);

/* More display class: https://github.com/moononournation/Arduino_GFX/wiki/Display-Class */
Arduino_GFX *gfx3 = new Arduino_NV3023(bus3, -1, 2 /* rotation */, false, 128, 128);

// Arduino_Canvas_Indexed *canvasGfx1 = new Arduino_Canvas_Indexed(64 /* width */, 128 /* height */, gfx1);

/*******************************************************************************
 * End of Arduino_GFX setting
 ******************************************************************************/

Arduino_GFX *gfx[3] = {gfx1, gfx2, gfx3};

PNG png;

int16_t w, h, xOffset, yOffset;

// Functions to access a file on the SD card
File pngFile;

void *myOpen(const char *filename, int32_t *size)
{

    pngFile = LittleFS.open(filename, "r");
    // pngFile = SPIFFS.open(filename, "r");

    if (!pngFile || pngFile.isDirectory())
    {
        // Serial.println(F("ERROR: Failed to open  file for reading"));
        // gfx2->println(F("ERROR: Failed to open  file for reading"));
    }
    else
    {
        *size = pngFile.size();
        // Serial.printf("Opened '%s', size: %d\n", filename, *size);
    }

    return &pngFile;
}

void myClose(void *handle)
{
    if (pngFile)
        pngFile.close();
}

int32_t myRead(PNGFILE *handle, uint8_t *buffer, int32_t length)
{
    if (!pngFile)
        return 0;
    return pngFile.read(buffer, length);
}

int32_t mySeek(PNGFILE *handle, int32_t position)
{
    if (!pngFile)
        return 0;
    return pngFile.seek(position);
}

// Function to draw pixels to the display
void PNGDraw1(PNGDRAW *pDraw)
{
    uint16_t usPixels[320];
    uint8_t usMask[320];

    // Serial.printf("Draw pos = 0,%d. size = %d x 1\n", pDraw->y, pDraw->iWidth);
    png.getLineAsRGB565(pDraw, usPixels, PNG_RGB565_LITTLE_ENDIAN, 0x00000000);
    png.getAlphaMask(pDraw, usMask, 1);
    gfx1->draw16bitRGBBitmap(xOffset, yOffset + pDraw->y, usPixels, pDraw->iWidth, 1);
}

void PNGDraw2(PNGDRAW *pDraw)
{
    uint16_t usPixels[320];
    uint8_t usMask[320];

    // Serial.printf("Draw pos = 0,%d. size = %d x 1\n", pDraw->y, pDraw->iWidth);
    png.getLineAsRGB565(pDraw, usPixels, PNG_RGB565_LITTLE_ENDIAN, 0x00000000);
    png.getAlphaMask(pDraw, usMask, 1);
    gfx2->draw16bitRGBBitmap(xOffset, yOffset + pDraw->y, usPixels, pDraw->iWidth, 1);
}
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

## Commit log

2023-11-08 add pcb
    [BOM_2.0__2023-11-07.xlsx]
2023-11-15 add stl&pannel
    [外壳 _面板.stl, 外壳_刻字.stl, 旋钮_光面.stl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]
2023-11-15 add software
    [custom.csv, custom_8MB.csv, partition_custom.csv]
2023-11-15 add c source
    [custom.csv, custom_8MB.csv, partition_custom.csv]
2023-11-15 add 2.4
    [BOM_2.4__2023-11-15.xlsx]
2023-11-15 add stl for pcb 2.4
    [旋钮_光面_2.4.stl, 旋钮_纹理_2.4.stl]
2023-11-21 update stl
    [plus_外壳 _面板_pla.stl, plus_旋钮_纹理_pla.stl, plus_盖板_pla.stl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]
2023-11-21 update sw 1.2.0
    - 屏蔽天气、pcstate
    - 增加宏定义控制audio的使用，在platform.ini中进行开关
    - 快捷键，可以自定义按键，填充数组内容即可
    - audio存在一个bug，若播放声音后，boot按钮（左数第三个）会失效；暂时解决，待后续跟进
    - 在时钟界面，会整点报时
2023-11-21 add stl readme
2023-12-16 fix and add stl
    [plus_外壳 _pla_面板_与亚克力盖板配合.stl, plus_旋钮_纹理_pla.stl, 外壳 _面板.stl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]
2024-03-20 add sw 1.2.2 ble
    适配硬件2.5版本，增加按键灯效，修复web错误
    [custom.csv, custom_8MB.csv, partition_custom.csv]
2024-04-17 ble 1.2.3
    ### 20240417 【v1.2.3】
    - 更新图形库arduino_gfx 1.4.6
    - 在wifi配置页面增加编码器的参数配置（一般为2或者4）
    - 显示界面的字体调整
    - 显示屏增加OTA进度条指示
    - b站界面调整
